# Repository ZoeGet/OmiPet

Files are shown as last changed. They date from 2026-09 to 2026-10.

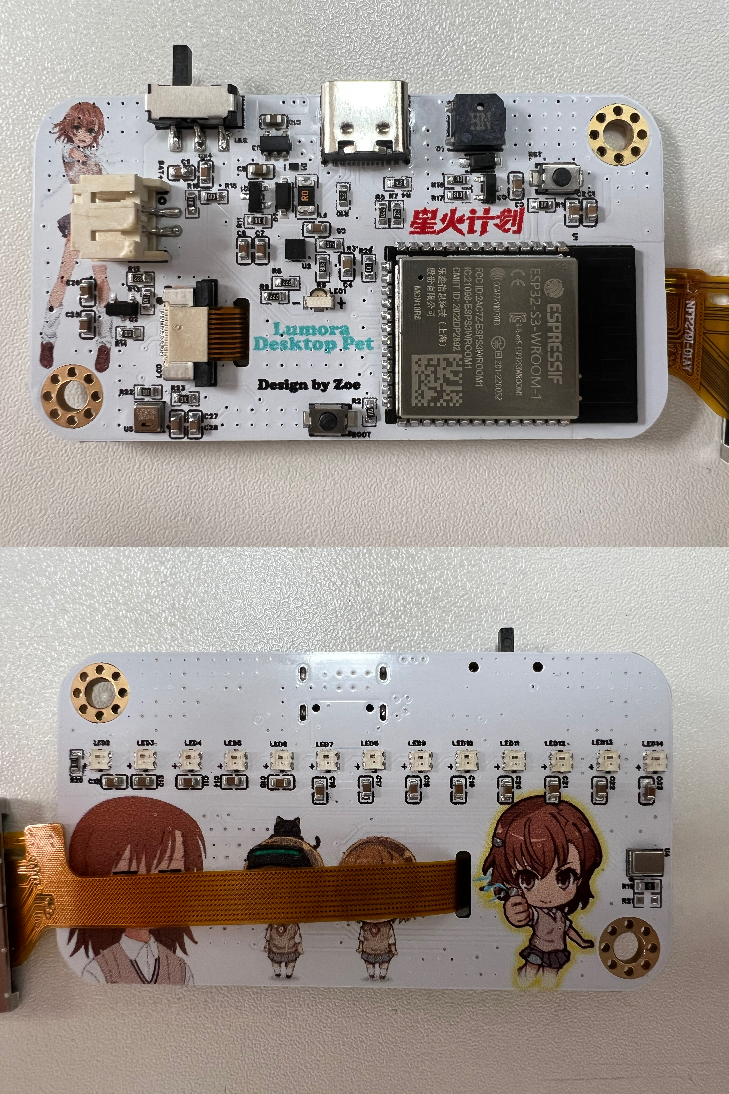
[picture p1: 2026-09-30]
Hardware/Images/Welding.jpg

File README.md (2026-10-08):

# OmiPet

OmiPet 是一个面向桌面陪伴场景的开源软硬件项目：它以 ESP32-S3 为核心，集成横向显示的彩色 LCD、温湿度传感器、灯带、蜂鸣器和数字麦克风，逐步实现桌面宠物、环境感知和离线语音交互。

> **English** — OmiPet is an open-source desktop companion project built around an ESP32-S3. It combines a landscape-oriented color LCD, environmental sensing, addressable LEDs, a buzzer, and an I²S digital microphone with an experimental offline voice interaction path.

## 项目状态 / Project Status

当前项目已经完成基础硬件驱动和第一阶段麦克风采集验证：

- NV3007 `142 × 428` LCD 基础驱动和桌面宠物 UI。
- AHT20 温湿度采集、CRC 校验和整机热影响补偿。
- `13` 颗 WS2812B-2020-V6 灯带驱动。
- 灯带常亮颜色、彩虹、呼吸、左右往返扫描和中心扩散回收动效，并支持离线语音切换。
- 无源蜂鸣器驱动。
- Wi-Fi 异步连接和手机网页配网门户。
- Wi-Fi 连接后通过 NTP 获取本地时间和日期；断网时显示占位符，不使用编译时间或假时间。
- BAT_ADC 电池电压采样和单节锂电估算电量显示；百分比仍需结合实测电池曲线校准。
- ICS-43434 原始 I²S 采集、RMS 音量分析、自适应语音活动检测和 16-bit PCM 音频帧适配。
- ESP-SR v1.2.0 中文 MultiNet `mn6_cn` 命令识别、独立模型分区和自定义短语“老鼠狒狒”实验链路。

当前固件不启用 WakeNet，也不把现成唤醒词冒充为产品唤醒词；“老鼠狒狒”通过中文 MultiNet 自定义命令词表作为唤醒入口，仍属于低延迟和误识别特性待继续验证的实验方案。

> **English** — The current firmware includes the display, environmental sensor, LED strip, passive buzzer, Wi-Fi provisioning, verified ICS-43434 I²S capture, and an ESP-SR v1.2.0 Chinese MultiNet `mn6_cn` command-recognition path using the separate model partition. WakeNet is disabled; “老鼠狒狒” is registered as a custom MultiNet phrase and remains an experimental wake-entry strategy whose latency and false-trigger behavior still require validation.

## 功能概览 / Features

| 模块 / Module | 当前实现 / Current implementation |
| --- | --- |
| 主控 / MCU | ESP32-S3-WROOM-1-N16R8，Arduino + ESP-IDF framework |
| 屏幕 / Display | NV3007，`142 × 428`，4-wire SPI |
| 环境传感器 / Environment | AHT20，I²C，GPIO38/39 |
| 灯带 / LED strip | 13 × WS2812B-2020-V6，GPIO47 |
| 蜂鸣器 / Buzzer | 无源磁式蜂鸣器，GPIO4 控制 / Passive magnetic buzzer on GPIO4 |
| 麦克风 / Microphone | ICS-43434，I²S，GPIO5/6/7 |
| 配网 / Provisioning | WiFiManager 手机网页配网 / WiFiManager captive portal |
| 时间 / Time | NTP 联网校时，默认 UTC+8；离线显示 `--:--` 和 `----/--/--` / NTP time sync, UTC+8 default; placeholders offline |
| 电池 / Battery | GPIO13 分压采样，显示电压和基于单节锂电静置电压的估算百分比 / GPIO13 divider sampling with voltage and estimated single-cell Li-ion percentage |

## 麦克风与 I²S / Microphone and I²S

当前固件使用 ESP32-S3 Arduino 框架内置的 ESP-IDF 旧版 I²S 驱动接口 `<driver/i2s.h>`，没有额外安装 ICS-43434 专用库。驱动直接调用 `i2s_driver_install()`、`i2s_set_pin()` 和 `i2s_read()`。

> **English** — The microphone driver uses the ESP-IDF I²S driver bundled with the ESP32-S3 Arduino framework. No dedicated ICS-43434 library is required.

### 硬件连接 / Hardware mapping

| ICS-43434 信号 / Signal | ESP32-S3 GPIO | 说明 / Description |
| --- | ---: | --- |
| `SCK` / BCLK | `GPIO5` | ESP32-S3 输出位时钟 / Bit clock generated by ESP32-S3 |
| `WS` / LRCLK | `GPIO6` | 字选择时钟 / Word-select clock |
| `SD` | `GPIO7` | 麦克风串行数据输出 / Microphone serial data output |
| `LR` | 由硬件电阻配置 | 决定左/右声道槽 / Selects the left or right I²S slot |

### 当前有效声道 / Active channel

**当前固件明确使用 I²S 右声道槽（`MicChannel::Right`）。**

这是根据当前实物测试确认的：原始双槽数据中只有右声道槽出现非零采样，左声道槽为零。因此 `Firmware/src/main.cpp` 会显式调用：

```cpp
OmiPetAudio::microphone.begin(
    OmiPetAudio::kMicDefaultSampleRateHz,
    OmiPetAudio::MicChannel::Right);
```

对应代码位于 [`Firmware/src/main.cpp`](Firmware/src/main.cpp) 和 [`Firmware/include/ics43434_mic.h`](Firmware/include/ics43434_mic.h)。如果更换 PCB、修改 `LR` 电阻或更换麦克风装配方向，需要重新确认有效声道，并同步修改 `MicChannel::Right`。

> **English** — The current firmware explicitly uses the **right I²S slot** (`MicChannel::Right`). This was verified on the assembled hardware because the right slot contains non-zero samples while the left slot remains zero. Re-check the slot if the PCB `LR` configuration or microphone assembly changes.

### 当前音频参数 / Current audio parameters

- 采样率：`16 kHz` / Sample rate: `16 kHz`
- 接收槽宽：`32-bit` / Receive slot width: `32-bit`
- 有效数据：ICS-43434 的 `24-bit` 数据，固件右移 8 位后用于音量分析 / 24-bit microphone data shifted by 8 bits for level analysis
- 音量窗口：约 `50 ms` / Level window: approximately `50 ms`
- 输出指标：`avg_abs`、`rms`、`peak`、`noise`、`threshold`、`speech`

### 语音交互状态 / Voice interaction state

当前固件使用 `16 kHz`、`16-bit`、单声道 PCM，将每次 `160` 个采样点的输入帧送入 AFE；AFE 以约 `512` 个采样点的输出帧驱动中文 MultiNet `mn6_cn`。词表包含灯带颜色/动效、亮度控制短语和自定义入口“老鼠狒狒”（命令 ID `1`）。识别到入口后，状态机播放约 `180 ms` 的三段式确认反馈，并进入 `LISTENING` 等待灯带控制指令。

### 灯带颜色与动效 / LED Colors and Effects

唤醒后说出颜色或动效命令即可切换灯带。颜色命令会保留当前动效，不会强制切换成常亮；彩色灯光使用彩虹动效，呼吸灯、跑马灯和扩散灯由主循环以非阻塞方式推进，使用约 `12 ms` 的时间驱动帧。三个动效默认使用纯色：呼吸灯为纯蓝、跑马灯为纯绿、扩散灯为纯红；动画只改变亮度，不把其他颜色混入当前颜色。跑马灯和扩散灯始终保留全灯带底光，并用连续渐变高光移动，避免灯珠逐颗跳变或完全熄灭。支持的动效说法包括“彩色”“彩色灯光”“彩色灯”“呼吸灯”“跑马灯”“扩散灯”；RGB 语音词条已删除；颜色命令支持“红色灯光/红色灯”等表达；还支持“开灯”“开启灯光”“一直亮”“关灯”和“关闭灯光”。亮度命令仍以 `16/255` 为步长调整全局亮度，“调亮一点/调暗一点”中的“调”使用拼音 `tiao`。

> **English** — After the custom wake entry, use colorful lights, breathing lights, running lights, or expanding lights. Color commands keep the active effect instead of forcing solid mode. The default effect colors are pure blue for breathing, pure green for running lights, and pure red for expanding lights; animation changes brightness without mixing hues. Running and expanding effects keep a base light on every pixel and add a smooth moving gradient. The brightness commands use `tiao` for 调, as in `tiao liang yi dian` and `tiao an yi dian`.

AFE 和 I²S 始终持续运行，但 VAD 只在检测到语音以及语音结束后的 `1.2 s` 尾窗内调用 MultiNet；这样避免待机时持续推理造成 CPU 调度和看门狗风险，同时尽量保留词尾。该门控策略不会承诺每次都在说话过程中返回，MultiNet 本身仍可能需要积累判定窗口。

> **English** — The firmware uses `16 kHz`, `16-bit`, mono PCM. It feeds `160`-sample input frames into AFE, which produces approximately `512`-sample frames for Chinese MultiNet `mn6_cn`. The phrase list contains brightness commands and the custom “老鼠狒狒” entry (command ID `1`). After detection, the state machine plays an approximately `180 ms` three-phase acknowledgement and listens for natural-language commands such as “亮一点” or “暗一点”.

I²S and AFE remain active continuously, while VAD gates MultiNet detection to speech activity plus a `1.2 s` hangover. This reduces idle inference load and watchdog risk while preserving phrase endings; it does not guarantee that MultiNet returns before the speaker finishes a phrase.

确认音播放期间以及结束后的 200 ms 内，VAD 会暂时抑制语音状态更新，但 I²S/PCM 仍持续采集，避免蜂鸣器回采触发语音开始事件。

> **English** — During the acknowledgement tone and for 200 ms afterward, VAD state updates are temporarily suppressed while I²S/PCM capture continues, preventing buzzer feedback from triggering speech-start events.

## 语音技术栈与唤醒词架构 / Voice Stack and Wake Phrase Architecture

### 技术栈 / Technology stack

当前语音功能采用 **Arduino 应用层 + ESP-IDF 底层 + ESP-SR 语音组件**，不是只依赖 Arduino 库的纯软件实现：

| 层级 / Layer | 当前实现 / Current implementation |
| --- | --- |
| 构建系统 / Build system | PlatformIO，`framework = arduino, espidf` |
| 应用逻辑 / Application logic | Arduino `setup()`/`loop()`、GPIO、灯带、蜂鸣器、UI 和状态机 |
| 音频底层 / Audio layer | ESP-IDF 旧版 I²S 驱动 `<driver/i2s.h>`，驱动 ICS-43434 |
| 语音前端 / Speech front end | ESP-SR AFE，负责音频预处理、AGC 和 VAD |
| 命令识别 / Command recognition | ESP-SR v1.2.0 中文 MultiNet `mn6_cn` |
| 模型存储 / Model storage | `model` 分区中的 SPIFFS 模型镜像 |
| 内存与芯片 / Memory and chip | ESP32-S3-WROOM-1-N16R8，OPI PSRAM，模型和 AFE 缓冲优先使用 PSRAM |

Arduino 负责设备业务和主循环；ESP-IDF 提供 I²S、FreeRTOS 调度和底层硬件接口；ESP-SR 提供 AFE、MultiNet 接口和语音模型。三者是同一份固件中的分层协作关系，不是互相替代的三套方案。

> **English** — The voice feature uses an **Arduino application layer + ESP-IDF low-level APIs + ESP-SR speech components**. Arduino handles `setup()`/`loop()`, device behavior, LEDs, buzzer, UI, and state transitions. ESP-IDF supplies I²S, scheduling, and hardware-level services. ESP-SR supplies the AFE, VAD, MultiNet interfaces, and speech models. This is an Arduino-based application built on the ESP-IDF component layer, not an Arduino-only library implementation.

### 音频处理流程 / Audio processing pipeline

```text
ICS-43434 I²S
    ↓
ESP-IDF I²S RX（GPIO5/GPIO6/GPIO7，16 kHz，32-bit slot）
    ↓
右声道槽提取与 PCM16 转换
    ↓
160-sample PCM frame queue
    ↓
ESP-SR AFE（持续 feed/fetch，包含 VAD）
    ↓
VAD 语音窗口 + 1.2 s 尾窗门控
    ↓
ESP-SR MultiNet `mn6_cn`
    ↓
命令 ID → 唤醒状态机或灯带业务
```

I²S、PCM 队列和 AFE 会持续运行，但 MultiNet 只在检测到语音活动或最近 `1.2 s` 的语音尾窗内进行判定。这样可以避免空闲时持续运行 MultiNet 引起 CPU 调度压力和看门狗风险，同时尽量保留词尾音频。

### “老鼠狒狒”如何实现 / How “老鼠狒狒” is implemented

当前并没有把“老鼠狒狒”写成 WakeNet 模型名称，也没有把它伪装成官方唤醒词。它是中文 MultiNet 命令词表中的一个自定义拼音短语：

```text
1 lao shu fei fei
```

个人配置位于 `Firmware/include/voice_command_config.h`。构建前，`Firmware/scripts/generate_model.py` 会先解析这个文件，将全部命令同步到 `Firmware/scripts/multinet_commands_cn.txt`，再把词表复制到 `target/fst/commands_cn.txt`，生成并加入 PlatformIO 的 `model` 分区镜像。运行时，`Firmware/src/multinet_command_recognizer.cpp` 会通过 ESP-SR 的命令词 API 注册同一组拼音和命令 ID，因此应用固件与模型使用同一份配置。

识别到命令 ID `1` 后，主循环将它解释为自定义唤醒入口：

1. 清空上一段 AFE/MultiNet 上下文；
2. 通知 `VoiceController` 进入 `LISTENING`；
3. 播放非阻塞双音确认反馈；
4. 在超时时间内等待 ID `2` 或 ID `3`；
5. 按 ID `2/3` 将亮度增加或降低 `16/255`，然后回到持续监听。

命令词的唯一修改入口是 `Firmware/include/voice_command_config.h`。修改或新增数组项即可维护唤醒词、同义表达和后续命令；不要直接修改同步后的 `Firmware/scripts/multinet_commands_cn.txt`，也不要修改自动生成的 `Firmware/include/generated_multinet_commands.h`。构建检查会拒绝空配置、重复短语、非正 ID、非法拼音、超过 MultiNet 长度/数量上限的配置，并确保 ID `1/2/3` 仍然存在且 ID `1` 只有一条。

更换或新增步骤：编辑 `Firmware/include/voice_command_config.h` → 修改/增加 `{命令ID, "无声调拼音"}` → 重新构建 → PlatformIO 自动同步词表、生成运行时表并把 `model.bin` 加入烧录列表 → 将应用固件和模型分区一起烧录 → 查看 `[ASR] continuous experiment wake_id=1 phrase=...` 日志并实测。新增命令词会自动注册，但要让设备执行新的业务动作，还必须在 `Firmware/src/main.cpp` 中为该命令 ID 增加业务分派；配置入口不会凭空生成未实现的业务逻辑。

因此，“唤醒词”在当前固件中准确的技术名称是：**MultiNet 自定义命令词入口**，而不是独立的 WakeNet 唤醒模型。

> **English** — “老鼠狒狒” is not a WakeNet model name and is not presented as an official wake word. It is registered as the custom Chinese MultiNet phrase `lao shu fei fei` with command ID `1`. The personal configuration entry is `Firmware/include/voice_command_config.h`; the build synchronizes every configured phrase to the model input, validates limits and IDs, generates the runtime table, and adds the model image to the PlatformIO flash list. New phrases are registered automatically, but a new command ID still needs a corresponding business handler in `Firmware/src/main.cpp`. Changing the tone-free pinyin requires rebuilding and reflashing both the application and the model partition, followed by recognition testing; it is not a runtime setting and arbitrary phrases are not guaranteed to work reliably. The accurate technical description is **a MultiNet custom command entry used as an experimental wake trigger**, not a standalone WakeNet model.

### 为什么不用现成 WakeNet / Why the supplied WakeNet model is not used

WakeNet 是专门的唤醒模型，但当前 ESP-SR 模型包中的现成模型对应固定唤醒短语，例如 `wn9_hiesp` 对应 `Hi ESP`。把配置中的字符串改成“老鼠狒狒”，不会改变神经网络已经训练好的识别目标；真正的自定义 WakeNet 需要与目标短语匹配的定制模型，并且还要重新完成模型打包、容量确认、误唤醒率和漏唤醒率验证。

本项目当前没有“老鼠狒狒”的定制 WakeNet 模型，而项目目标又明确要求自定义唤醒词，因此不能直接使用现成 WakeNet 冒充已经实现了目标词。当前配置明确关闭 WakeNet：`CONFIG_USE_WAKENET=n`，运行时 AFE 配置也设置 `wakenet_init = false`。

选择 MultiNet 自定义命令词作为实验入口，是因为它允许我们在现有中文 `mn6_cn` 模型上注册自己的拼音短语，不需要等待或伪造一个不存在的定制 WakeNet 模型。代价是 MultiNet 不是低延迟专用唤醒引擎：当前实测“老鼠狒狒”通常在语音结束后还要等待约 `1.1–1.3 s`，并且仍需继续验证误识别、误触发和长期稳定性。

> **English** — WakeNet is a dedicated wake-word model, but the bundled model is trained for fixed phrases such as `Hi ESP`. Changing a configuration string does not retrain the neural network. A real custom WakeNet phrase requires a matching custom model, followed by model packaging, capacity checks, false-trigger testing, and missed-wake testing. Because this project does not currently have a custom “老鼠狒狒” WakeNet model, WakeNet is explicitly disabled. MultiNet custom commands provide a workable offline experimental entry, but they are not a low-latency dedicated wake engine; the current measured wake-result delay is typically about `1.1–1.3 s` after speech ends.

### 关键构建文件 / Important build files

- `Firmware/platformio.ini`：声明 Arduino + ESP-IDF 双框架、PlatformIO 环境和模型预构建脚本。
- `Firmware/CMakeLists.txt`：ESP-IDF 工程入口。
- `Firmware/src/CMakeLists.txt`：注册固件源文件并声明 `esp-sr` 组件依赖。
- `Firmware/sdkconfig.defaults`：启用 AFE、中文 MultiNet、模型分区、16 MB Flash 和 OPI PSRAM，并明确关闭 WakeNet。
- `Firmware/components/esp-sr`：ESP-SR v1.2.0 子模块，提供 AFE/MultiNet 头文件、库和模型工具。
- `Firmware/include/voice_command_config.h`：个人语音命令配置入口；集中维护命令 ID 和无声调拼音短语，ID `1` 为唤醒词，ID `2/3` 为亮度，ID `4–16` 为颜色和动效。
- `Firmware/include/led_controller.h`、`Firmware/src/led_controller.cpp`：分离的 WS2812B 硬件缓存 `Strip` 和非阻塞动画控制器 `EffectController`。
- `Firmware/scripts/check_multinet_commands.py`：构建前解析个人配置、同步词表、校验命令 ID/重复短语/容量，并生成 `Firmware/include/generated_multinet_commands.h`。
- `Firmware/scripts/multinet_commands_cn.txt`：由构建流程从个人配置自动同步的 MultiNet 词表，不是推荐的手动编辑入口。
- `Firmware/scripts/generate_model.py`：将 ESP-SR 模型和项目词表打包成 `model.bin`，并将其加入 PlatformIO 烧录流程。

这些文件共同组成当前语音架构；不能因为没有使用 WakeNet 就删除 `CMakeLists.txt`、`sdkconfig.defaults` 或整个 `esp-sr` 目录。

## 硬件资料 / Hardware Resources

- [原理图 / Schematic](Hardware/Schematic/Omi_Schematic.pdf)
- [焊接完成照片 / Assembled board photo](Hardware/Images/Welding.jpg)
- [前壳 / Front cover](Hardware/Enclosure/Frontcover.STEP)
- [后壳 / Back cover](Hardware/Enclosure/Backcover.STEP)

厂家提供的原始 LCD 资料目录不属于公开固件源代码的一部分，相关目录按 `.gitignore` 规则排除，避免将供应商文件和构建产物混入项目仓库。

## 仓库结构 / Repository Layout

```text
OmiPet/
├─ Firmware/                 # PlatformIO firmware / PlatformIO 固件
│  ├─ include/               # Public headers / 公共头文件
│  ├─ lib/                   # Local drivers / 本地驱动
│  ├─ src/                   # Application sources / 应用源码
│  └─ platformio.ini         # Build configuration / 构建配置
├─ Hardware/
│  ├─ Schematic/             # Schematic files / 原理图
│  ├─ Images/                # Board photos / 实物照片
│  └─ Enclosure/             # STEP enclosure models / STEP 外壳模型
├─ README.md
└─ .gitignore
```

## 快速开始 / Quick Start

### 环境要求 / Requirements

- VS Code + PlatformIO
- ESP32-S3-WROOM-1-N16R8 或兼容的 ESP32-S3 开发板
- USB 数据线
- Arduino framework（由 PlatformIO 自动安装）

### 编译、烧录和串口监视 / Build, Upload, and Monitor

在仓库根目录执行：

```powershell
cd Firmware
pio run
pio run -t upload
pio device monitor -b 115200
```

ESP32-S3 使用原生 USB CDC 输出串口日志。当前运行状态可以通过以下日志确认：

```text
[SYS] alive ms=... mic=ok wifi=offline
[TIME] NTP synchronized 2026-10-04 12:34
[MIC] frames=800 avg_abs=... rms=... peak=... noise=... threshold=... speech=no
```

当对着麦克风说话时，`rms` 和 `peak` 应明显上升，并可能出现 `speech=yes`。

首次没有保存 Wi-Fi 配置时，设备会启动配网热点并显示门户地址；使用手机连接热点后，在网页中选择附近 Wi-Fi 并填写密码即可完成配网。

联网后固件通过 `ntp.aliyun.com`、`pool.ntp.org` 和 `time.nist.gov` 获取时间，按 UTC+8 显示；首次同步失败每 10 秒重试，已同步后每 1 小时重新校时。主循环在音频处理前后刷新网络和时间状态，减少语音推理造成的 UI 延迟。只有 Wi-Fi 已连接且 NTP 已同步时才显示时间；Wi-Fi 断开或 NTP 尚未同步时，时间显示为 `--:--`，日期显示为 `----/--/--`，不会回退到编译时间。

## 温湿度补偿说明 / Sensor Compensation

AHT20 上电初期的读数通常接近环境值。随着 ESP32-S3、LCD 背光、电源区域和灯带持续工作，传感器所在 PCB 区域会升温，导致温度偏高；相对湿度也会因此表现为偏低。

当前固件采用针对本设备实测得到的经验补偿：温度约减 `4 °C`，湿度约加 `9 %RH`。这不是 AHT20 厂家提供的固定参数，只适用于当前 PCB、负载、背光、灯带亮度、供电和外壳条件。若这些条件改变，应重新进行现场校准。

> **English** — The temperature and humidity offsets are device-specific field calibration values, not sensor-datasheet constants. Recalibrate them if the thermal layout, load, lighting, power source, or enclosure changes.

## 开发路线 / Roadmap

- [x] NV3007 LCD 基础驱动和 UI / Basic display driver and UI
- [x] AHT20 读取、校验和补偿 / AHT20 reading, validation, and compensation
- [x] WS2812B 灯带驱动 / WS2812B strip driver
- [x] 无源蜂鸣器驱动 / Passive buzzer driver
- [x] Wi-Fi 网页配网 / Wi-Fi captive-portal provisioning
- [x] 联网 NTP 时间和日期显示、每小时复校 / Network NTP time/date display with hourly resynchronization
- [x] ICS-43434 原始 I²S 采集 / Raw ICS-43434 I²S capture
- [x] 音量统计和基础语音活动检测 / Level statistics and basic speech activity detection
- [x] 16-bit PCM 音频帧适配 / 16-bit PCM audio frame adaptation
- [x] VAD 门控的 AFE/MultiNet 语音链路 / VAD-gated AFE/MultiNet voice pipeline
- [x] “老鼠狒狒”自定义短语入口 / Custom “老鼠狒狒” phrase entry
- [x] 唤醒后双音反馈状态机 / Post-wake dual-tone feedback state machine
- [x] MultiNet 自然语言亮度指令 / MultiNet natural-language brightness commands
- [ ] 降低 MultiNet 判定窗口延迟 / Reduce MultiNet decision-window latency
- [ ] 扩展语音驱动的设备动作 / Expand voice-controlled device actions

## 贡献与代码规范 / Contributing and Code Style

欢迎提交 Issue、改进建议和 Pull Request。提交代码前请确保：

- 修改范围聚焦，并说明对应的硬件或软件行为。
- 不提交 PlatformIO 构建目录、串口日志、临时文件、密钥或个人环境配置。
- 新增或修改的代码注释统一使用：`//  中文注释 / English comment`。
- 中文在前、英文在后，使用 `/` 分隔，`//` 后保留两个空格。
- 多行注释、命名空间注释、配置项说明和接口说明遵守同一格式。
- 硬件行为如未经实测确认，应在文档中明确标注为待验证。

更多协作约束见本地 `AGENTS.md`；该文件用于开发交接，默认不纳入公开仓库。

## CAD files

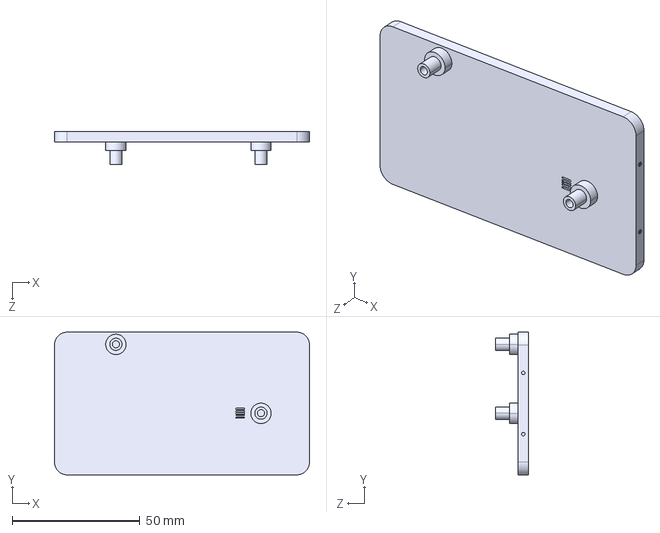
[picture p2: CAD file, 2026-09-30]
Hardware/Enclosure/Backcover.STEP
100.0 x 56.0 x 12.9 mm

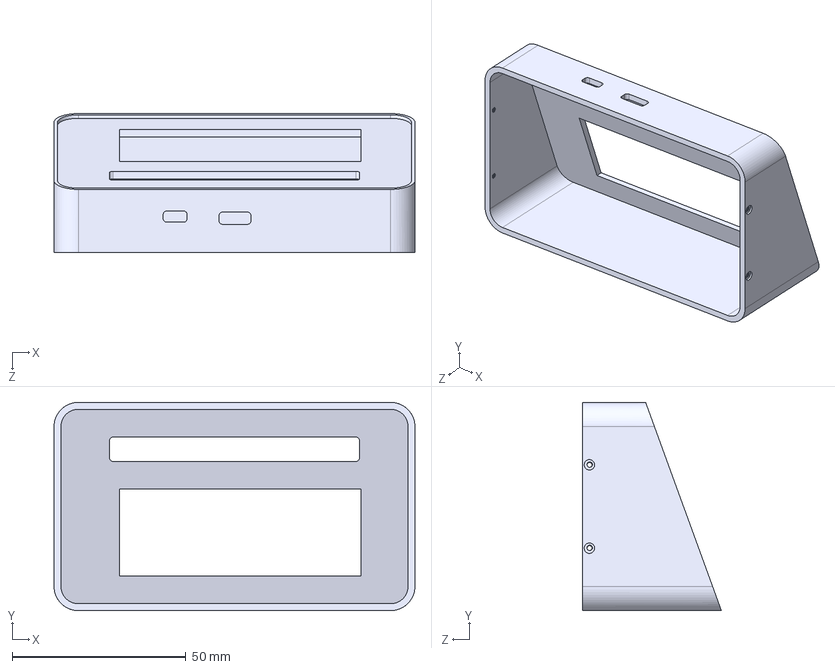
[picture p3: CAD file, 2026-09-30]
Hardware/Enclosure/Frontcover.STEP
104.0 x 60.0 x 40.0 mm

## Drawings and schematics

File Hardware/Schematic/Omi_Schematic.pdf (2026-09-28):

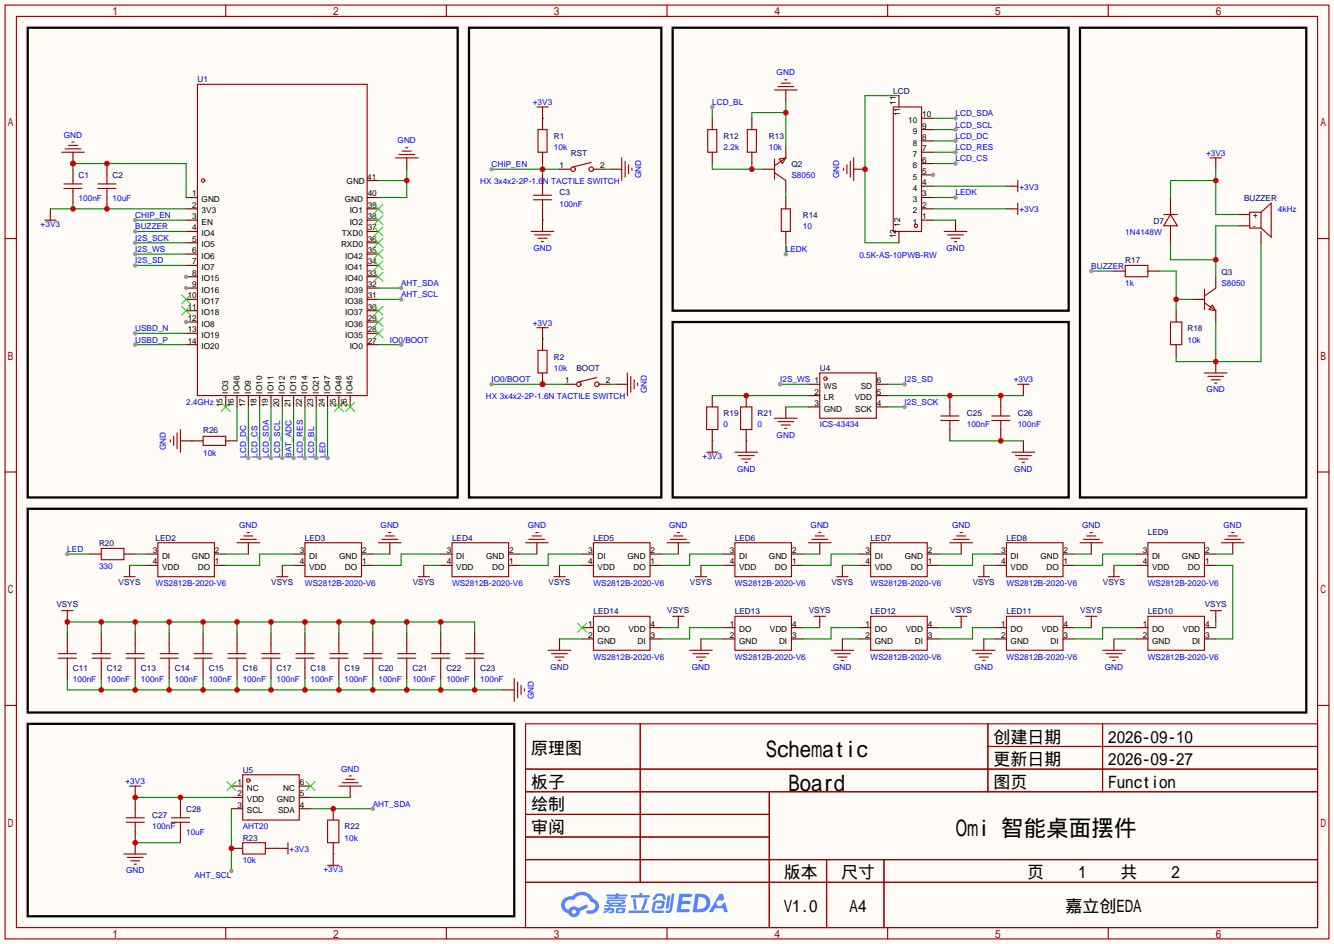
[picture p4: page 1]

原理图 | Schematic | 创建日期 | 2026-09-10

更新日期 | 2026-09-27

绘制 | Omi 智能桌面摆件
审阅

V1.0 | A4 | 嘉立创EDA

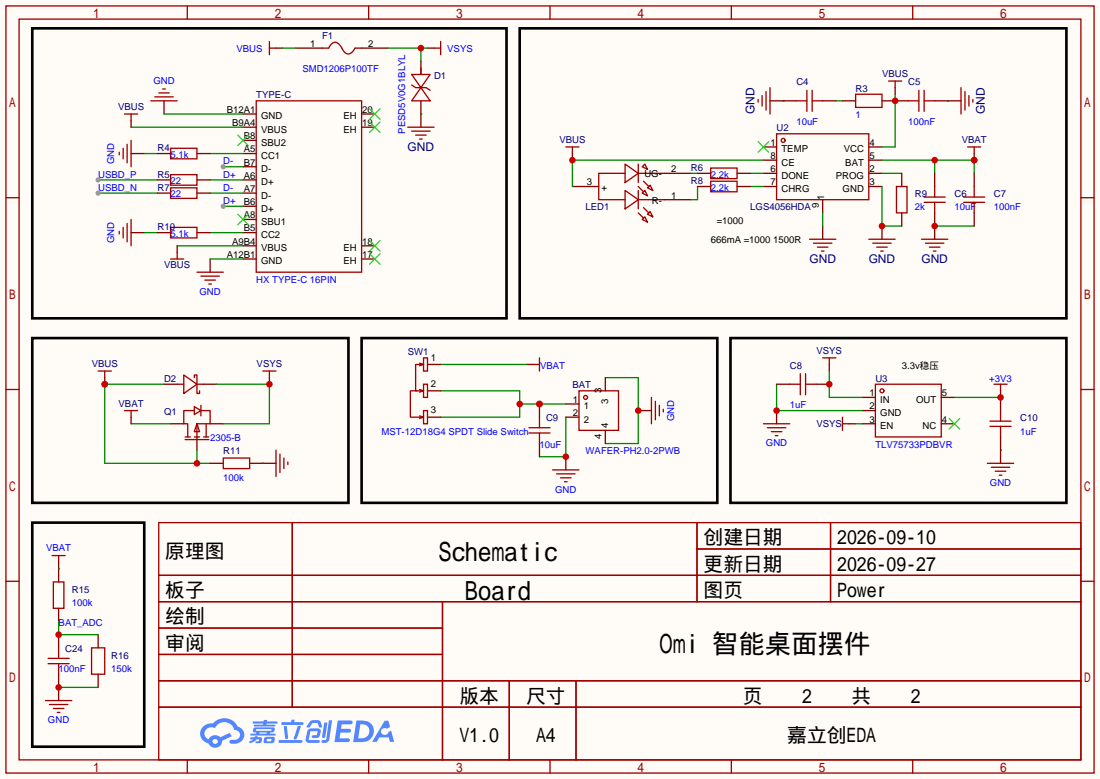
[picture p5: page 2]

MST-12D18G4 SPDT Slide Switch

原理图 | Schematic | 创建日期 | 2026-09-10

更新日期 | 2026-09-27

板子 | Board | 图页 | Power
绘制 | | Omi 智能桌面摆件
审阅

V1.0 | A4 | 嘉立创EDA

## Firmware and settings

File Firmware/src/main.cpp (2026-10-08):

#include <Arduino.h>
#include <algorithm>
#include <cmath>
#include <cstdint>
#include "aht20_sensor.h"
#include "battery_monitor.h"
#include "buzzer.h"
#include "NV3007_Display.h"
#include "led_controller.h"
#include "omi_pet_ui.h"
#include "time_service.h"
#include "wifi_manager.h"

//  OmiPet 固件主循环和模块编排 / OmiPet firmware entry point and module orchestration
#include "ics43434_mic.h"
#include "pcm_audio_frame_buffer.h"
#include "multinet_command_recognizer.h"
#include "voice_controller.h"

namespace {

//  音频链路为 I2S、PCM 队列、AFE、VAD 和 MultiNet 的串联流程 / The audio path chains I2S, PCM queue, AFE, VAD, and MultiNet
//  麦克风诊断窗口和周期参数 / Microphone diagnostic window and periodic timing parameters
constexpr size_t kMicDiagnosticFrameCount = 160;  //  每个麦克风诊断窗口的采样帧数 / Audio frames per microphone diagnostic window
constexpr size_t kMicDiagnosticWordCount = kMicDiagnosticFrameCount * 2;  //  双声道原始槽的样本字数量 / Raw sample words for both channel slots
constexpr uint32_t kMicWindowIntervalMs = 10;  //  麦克风诊断窗口处理间隔 / Microphone diagnostic-window interval
constexpr uint32_t kMicLogIntervalMs = 1000;  //  麦克风诊断日志输出间隔 / Microphone diagnostic log interval
constexpr uint32_t kSpeechDetectionHangoverMs = 1200;  //  语音结束后继续允许 MultiNet 检测的尾窗时间 / MultiNet detection hangover after speech ends
constexpr size_t kMaxCommandFramesPerLoop = 4;  //  单次主循环最多处理的命令音频帧数 / Maximum command audio frames processed per loop
constexpr uint32_t kMinimumSpeechStartRms = 10000;  //  从静音进入语音状态的最小 RMS / Minimum RMS to start speech state
constexpr uint32_t kMinimumSpeechHoldRms = 5000;  //  保持语音状态的最小 RMS / Minimum RMS to hold speech state
constexpr uint8_t kSpeechStartWindowCount = 3;  //  连续语音窗口达到此数后进入语音状态 / Speech windows required to enter speech state
constexpr uint8_t kSpeechEndWindowCount = 8;  //  连续安静窗口达到此数后退出语音状态 / Quiet windows required to leave speech state

//  麦克风采样、噪声底和 VAD 状态 / Microphone samples, noise floor, and VAD state
int32_t gMicDiagnosticWords[kMicDiagnosticWordCount] = {};  //  麦克风双声道原始样本窗口 / Raw stereo microphone sample window
uint32_t gLastMicWindowMs = 0;  //  上一次麦克风窗口处理时间 / Last microphone-window processing time
uint32_t gLastMicLogMs = 0;  //  上一次麦克风日志时间 / Last microphone diagnostic log time
uint32_t gLastSystemHeartbeatMs = 0;  //  上一次系统心跳时间 / Last system heartbeat time
uint32_t gMicNoiseFloorRms = 0;  //  自适应噪声底 RMS / Adaptive microphone noise-floor RMS
bool gMicNoiseFloorInitialized = false;  //  是否已经初始化噪声底 / Whether the noise floor is initialized
uint8_t gSpeechStartWindows = 0;  //  连续语音候选窗口计数 / Consecutive speech-candidate window count
uint8_t gSpeechQuietWindows = 0;  //  连续安静窗口计数 / Consecutive quiet-window count
bool gSpeechActive = false;  //  当前是否处于语音活动状态 / Whether speech is currently active
//  记录最近一次 VAD 语音活动，用于维持检测尾窗 / Track the latest VAD activity to maintain the detection hangover
uint32_t gLastSpeechActivityMs = 0;  //  最近一次语音活动时间 / Most recent speech-activity time
uint32_t gLastMicThreshold = 0;  //  最近一次动态语音判定阈值 / Most recent adaptive speech threshold
bool gLastSpeechCandidate = false;  //  最近一次窗口是否为语音候选 / Whether the latest window was a speech candidate

struct MicLevelStats {
  uint32_t averageAbsolute = 0;  //  窗口平均绝对振幅 / Window average absolute amplitude
  uint32_t rms = 0;  //  窗口均方根音量 / Window root-mean-square level
  uint32_t peak = 0;  //  窗口峰值振幅 / Window peak amplitude
  size_t frameCount = 0;  //  已统计的采样帧数 / Number of sampled frames included
};

MicLevelStats gLastMicStats;

//  命令音频队列和识别时间戳 / Command audio queue and recognition timestamps
OmiPetAudio::PcmAudioFrameBuffer gCommandAudioBuffer;  //  送入 AFE/MultiNet 的 PCM 帧队列 / PCM frame queue feeding AFE/MultiNet
int16_t gCommandPcmFrame[OmiPetAudio::kPcmAudioFrameSamples] = {};  //  当前待处理的 PCM 帧 / Current PCM frame being processed
uint32_t gCommandFrameCount = 0;  //  已处理的命令 PCM 帧数量 / Number of processed command PCM frames
uint32_t gLastAudioFrameLogMs = 0;  //  上一次音频帧日志时间 / Last audio-frame log time
uint32_t gSpeechStartAtMs = 0;  //  当前语音片段开始时间 / Start time of the current speech segment
uint32_t gSpeechStopAtMs = 0;  //  当前语音片段结束时间 / End time of the current speech segment
uint32_t gWakeAcceptedAtMs = 0;  //  最近一次唤醒被状态机接受的时间 / Time when the latest wake was accepted
bool gSpeechTimingValid = false;  //  当前语音时间戳是否有效 / Whether current speech timestamps are valid

//  执行一个已识别的灯带命令 / Execute one recognized LED command
bool executeLedCommand(int commandId) {
  using namespace OmiPetAudio;
  switch (commandId) {
    case kIncreaseBrightnessCommandId: {
      const int updatedBrightness = std::max(
          0, std::min(static_cast<int>(OmiPetLed::strip.brightness()) + 16,
                      255));
      OmiPetLed::strip.setBrightness(static_cast<uint8_t>(updatedBrightness));
      OmiPetLed::strip.show();
      Serial.printf("[LED] brightness=%d command=increase\n",
                    updatedBrightness);
      return true;
    }
    case kDecreaseBrightnessCommandId: {
      const int updatedBrightness = std::max(
          0, std::min(static_cast<int>(OmiPetLed::strip.brightness()) - 16,
                      255));
      OmiPetLed::strip.setBrightness(static_cast<uint8_t>(updatedBrightness));
      OmiPetLed::strip.show();
      Serial.printf("[LED] brightness=%d command=decrease\n",
                    updatedBrightness);
      return true;
    }
    case kRedColorCommandId:
      OmiPetLed::effects.setColor(255, 0, 0);
      Serial.println("[LED] color=red");
      return true;
    case kGreenColorCommandId:
      OmiPetLed::effects.setColor(0, 255, 0);
      Serial.println("[LED] color=green");
      return true;
    case kBlueColorCommandId:
      OmiPetLed::effects.setColor(0, 0, 255);
      Serial.println("[LED] color=blue");
      return true;
    case kYellowColorCommandId:
      OmiPetLed::effects.setColor(255, 160, 0);
      Serial.println("[LED] color=yellow");
      return true;
    case kPurpleColorCommandId:
      OmiPetLed::effects.setColor(180, 0, 255);
      Serial.println("[LED] color=purple");
      return true;
    case kCyanColorCommandId:
      OmiPetLed::effects.setColor(0, 220, 255);
      Serial.println("[LED] color=cyan");
      return true;
    case kWhiteColorCommandId:
      OmiPetLed::effects.setColor(255, 255, 255);
      Serial.println("[LED] color=white");
      return true;
    case kRainbowEffectCommandId:
      OmiPetLed::effects.setRainbow();
      Serial.println("[LED] effect=rainbow");
      return true;
    case kBreatheEffectCommandId:
      OmiPetLed::effects.setBreathe();
      Serial.println("[LED] effect=breathe");
      return true;
    case kSweepEffectCommandId:
      OmiPetLed::effects.setSweep();
      Serial.println("[LED] effect=sweep");
      return true;
    case kCenterExpandEffectCommandId:
      OmiPetLed::effects.setCenterExpand();
      Serial.println("[LED] effect=center_expand");
      return true;
    case kSolidEffectCommandId:
      OmiPetLed::effects.setSolid();
      Serial.println("[LED] effect=solid");
      return true;
    case kOffEffectCommandId:
      OmiPetLed::effects.setOff();
      Serial.println("[LED] effect=off");
      return true;
    default:
      return false;
  }
}

//  计算选定声道的音量统计 / Calculate level statistics for the selected channel
MicLevelStats analyzeMicrophoneLevel(const int32_t* words, size_t wordCount,
                                     OmiPetAudio::MicChannel channel) {
  MicLevelStats stats;
  const size_t selectedSlot = static_cast<size_t>(channel);
  uint64_t absoluteSum = 0;
  uint64_t squareSum = 0;

  const size_t frameCount = wordCount / 2;
  for (size_t frame = 0; frame < frameCount; ++frame) {
    const int32_t rawSample = words[frame * 2 + selectedSlot];
    const int32_t sample = rawSample >> 8;
    const int64_t signedSample = sample;
    const uint64_t magnitude = signedSample < 0
                                   ? static_cast<uint64_t>(-signedSample)
                                   : static_cast<uint64_t>(signedSample);
    absoluteSum += magnitude;
    squareSum += magnitude * magnitude;
    stats.peak = std::max(stats.peak, static_cast<uint32_t>(magnitude));
    ++stats.frameCount;
  }

  if (stats.frameCount == 0U) {
    return stats;
  }

  stats.averageAbsolute =
      static_cast<uint32_t>(absoluteSum / stats.frameCount);
  stats.rms = static_cast<uint32_t>(
      std::sqrt(static_cast<double>(squareSum) / stats.frameCount));
  return stats;
}

//  根据动态噪声底估算语音候选状态 / Estimate speech candidacy from the adaptive noise floor
bool detectSpeech(uint32_t rms, uint32_t& threshold) {
  if (!gMicNoiseFloorInitialized) {
    gMicNoiseFloorRms = rms;
    gMicNoiseFloorInitialized = true;
  }

  const uint32_t thresholdMultiplier = gSpeechActive ? 2U : 3U;
  threshold = std::max(gMicNoiseFloorRms * thresholdMultiplier,
                       gMicNoiseFloorRms + 1000U);
  const uint32_t minimumRms =
      gSpeechActive ? kMinimumSpeechHoldRms : kMinimumSpeechStartRms;
  const bool speechDetected = rms > threshold && rms >= minimumRms;
  if (!speechDetected) {
    gMicNoiseFloorRms = (gMicNoiseFloorRms * 15U + rms) / 16U;
  }
  return speechDetected;
}

//  更新连续语音状态并应用迟滞 / Update continuous speech state with hysteresis
bool updateSpeechState(bool speechCandidate) {
  if (speechCandidate) {
    gSpeechQuietWindows = 0;
    if (!gSpeechActive) {
      if (gSpeechStartWindows < 255U) {
        ++gSpeechStartWindows;
      }
      if (gSpeechStartWindows >= kSpeechStartWindowCount) {
        gSpeechActive = true;
        gSpeechStartWindows = 0;
      }
    }
  } else {
    gSpeechStartWindows = 0;
    if (gSpeechActive) {
      if (gSpeechQuietWindows < 255U) {
        ++gSpeechQuietWindows;
      }
      if (gSpeechQuietWindows >= kSpeechEndWindowCount) {
        gSpeechActive = false;
        gSpeechQuietWindows = 0;
      }
    }
  }
  return gSpeechActive;
}

//  读取麦克风窗口、更新 VAD 状态，并把 PCM 帧送入识别队列 / Read microphone windows, update VAD, and queue PCM frames
//  每 10 ms 处理音频窗口，每秒打印一次诊断状态 / Process an audio window every 10 ms and print diagnostics once per second
void updateMicrophoneDiagnostic() {
  const uint32_t nowMs = millis();
  if (nowMs - gLastMicWindowMs < kMicWindowIntervalMs) {
    return;
  }
  gLastMicWindowMs = nowMs;

  if (!OmiPetAudio::microphone.initialized()) {
    if (nowMs - gLastMicLogMs >= kMicLogIntervalMs) {
      gLastMicLogMs = nowMs;
      Serial.println("[MIC] unavailable");
    }
    return;
  }

  const size_t wordCount = OmiPetAudio::microphone.readRawWords(
      gMicDiagnosticWords, kMicDiagnosticWordCount);
  if (wordCount == 0U) {
    if (nowMs - gLastMicLogMs >= kMicLogIntervalMs) {
      gLastMicLogMs = nowMs;
      Serial.println("[MIC] no samples");
    }
    return;
  }

  gLastMicStats = analyzeMicrophoneLevel(
      gMicDiagnosticWords, wordCount, OmiPetAudio::microphone.channel());
  if (OmiPetAudio::multiNetCommandRecognizer.available()) {
    //  无论是否允许识别，都先把音频送入 AFE 处理链 / Always feed audio into the AFE pipeline, even when detection is gated off
    gCommandAudioBuffer.pushInterleavedWords(
        gMicDiagnosticWords, wordCount, OmiPetAudio::microphone.channel());
  }
  const bool speechWasActive = gSpeechActive;
  if (OmiPetVoice::voice.speechInputSuppressed()) {
    gLastSpeechCandidate = false;
    gSpeechActive = false;
    gSpeechStartWindows = 0;
    gSpeechQuietWindows = 0;
  } else {
    gLastSpeechCandidate =
        detectSpeech(gLastMicStats.rms, gLastMicThreshold);
    if (gLastSpeechCandidate) {
      gLastSpeechActivityMs = nowMs;
    }
    updateSpeechState(gLastSpeechCandidate);
  }
  if (speechWasActive != gSpeechActive) {
    Serial.printf("[VAD] event=%s rms=%lu threshold=%lu\n",
                  gSpeechActive ? "start" : "stop",
                  static_cast<unsigned long>(gLastMicStats.rms),
                  static_cast<unsigned long>(gLastMicThreshold));
    if (gSpeechActive) {
      gSpeechStartAtMs = nowMs;
      gSpeechTimingValid = true;
      Serial.printf("[TIMING] speech_start ms=%lu\n",
                    static_cast<unsigned long>(gSpeechStartAtMs));
    } else {
      gSpeechStopAtMs = nowMs;
      Serial.printf("[TIMING] speech_stop ms=%lu duration_ms=%lu\n",
                    static_cast<unsigned long>(gSpeechStopAtMs),
                    gSpeechTimingValid
                        ? static_cast<unsigned long>(gSpeechStopAtMs -
                                                     gSpeechStartAtMs)
                        : 0UL);
    }
  }
  if (nowMs - gLastMicLogMs < kMicLogIntervalMs) {
    return;
  }
  gLastMicLogMs = nowMs;
  Serial.printf(
      "[MIC] frames=%u avg_abs=%lu rms=%lu peak=%lu noise=%lu threshold=%lu candidate=%s speech=%s start=%u quiet=%u\n",
      static_cast<unsigned>(gLastMicStats.frameCount),
      static_cast<unsigned long>(gLastMicStats.averageAbsolute),
      static_cast<unsigned long>(gLastMicStats.rms),
      static_cast<unsigned long>(gLastMicStats.peak),
      static_cast<unsigned long>(gMicNoiseFloorRms),
      static_cast<unsigned long>(gLastMicThreshold),
      gLastSpeechCandidate ? "yes" : "no",
      gSpeechActive ? "yes" : "no",
      static_cast<unsigned>(gSpeechStartWindows),
      static_cast<unsigned>(gSpeechQuietWindows));
}

//  将连续采集的 PCM 帧送入离线命令识别器 / Submit continuously captured PCM frames to the offline command recognizer
//  AFE 始终接收音频，allowDetection 只控制 MultiNet 是否实际判定 / AFE always receives audio; allowDetection only gates MultiNet decisions
void updateCommandAudioFrames() {
  size_t processedFrameCount = 0;
  while (gCommandAudioBuffer.popFrame(
             gCommandPcmFrame, OmiPetAudio::kPcmAudioFrameSamples) &&
         processedFrameCount < kMaxCommandFramesPerLoop) {
    ++processedFrameCount;
    const uint32_t nowMs = millis();
    //  AFE 持续运行，但只有语音活动或尾窗内才调用 MultiNet 推理 / Keep AFE running continuously, but invoke MultiNet only during speech or hangover
    const bool speechDetectionWindowOpen =
        gSpeechActive ||
        (gLastSpeechActivityMs != 0U &&
         nowMs - gLastSpeechActivityMs <= kSpeechDetectionHangoverMs);
    const bool allowDetection =
        speechDetectionWindowOpen &&
        !OmiPetVoice::voice.speechInputSuppressed();
    const uint32_t detectStartedAtMs = millis();
    const int commandId = OmiPetAudio::multiNetCommandRecognizer.processFrame(
        gCommandPcmFrame, OmiPetAudio::kPcmAudioFrameSamples,
        allowDetection);
    const uint32_t detectFinishedAtMs = millis();
    //  自定义词 ID=1 作为待机入口，识别后清空上一段模型上下文 / Use custom phrase ID 1 as the idle entry and clear the previous model context
    if (commandId == OmiPetAudio::kWakePhraseCommandId &&
        OmiPetVoice::voice.state() == OmiPetVoice::VoiceState::Idle) {
      const uint32_t speechAgeMs =
          gSpeechTimingValid ? detectFinishedAtMs - gSpeechStartAtMs : 0U;
      const uint32_t speechStopAgeMs =
          gSpeechTimingValid && gSpeechStopAtMs >= gSpeechStartAtMs
              ? detectFinishedAtMs - gSpeechStopAtMs
              : 0U;
      Serial.printf(
          "[TIMING] wake_result ms=%lu infer_ms=%lu since_speech_start_ms=%lu "
          "since_speech_stop_ms=%lu\n",
          static_cast<unsigned long>(detectFinishedAtMs),
          static_cast<unsigned long>(detectFinishedAtMs - detectStartedAtMs),
          static_cast<unsigned long>(speechAgeMs),
          static_cast<unsigned long>(speechStopAgeMs));
      OmiPetAudio::multiNetCommandRecognizer.reset();
      gCommandAudioBuffer.reset();
      Serial.println("[VOICE] continuous wake phrase detected");
      if (OmiPetVoice::voice.notifyWakeWordDetected()) {
        gWakeAcceptedAtMs = millis();
        Serial.printf("[TIMING] wake_accepted ms=%lu\n",
                      static_cast<unsigned long>(gWakeAcceptedAtMs));
      }
      continue;
    }
    //  唤醒后接受灯带控制命令，执行成功后回到持续监听 / Accept LED commands after wake-up, then return to continuous listening
    if (OmiPetVoice::voice.listeningForCommand() &&
        commandId >= OmiPetAudio::kIncreaseBrightnessCommandId &&
        commandId <= OmiPetAudio::kCenterExpandEffectCommandId) {
      const uint32_t speechAgeMs =
          gSpeechTimingValid ? detectFinishedAtMs - gSpeechStartAtMs : 0U;
      const uint32_t wakeAgeMs = gWakeAcceptedAtMs != 0U
                                      ? detectFinishedAtMs - gWakeAcceptedAtMs
                                      : 0U;
      Serial.printf(
          "[TIMING] command_result ms=%lu infer_ms=%lu "
          "since_speech_start_ms=%lu since_wake_accepted_ms=%lu\n",
          static_cast<unsigned long>(detectFinishedAtMs),
          static_cast<unsigned long>(detectFinishedAtMs - detectStartedAtMs),
          static_cast<unsigned long>(speechAgeMs),
          static_cast<unsigned long>(wakeAgeMs));
      const bool executed = executeLedCommand(commandId);
      if (!executed) {
        continue;
      }
      Serial.printf("[TIMING] command_executed ms=%lu detect_to_led_ms=%lu\n",
                    static_cast<unsigned long>(millis()),
                    static_cast<unsigned long>(millis() - detectFinishedAtMs));
      OmiPetAudio::multiNetCommandRecognizer.reset();
      OmiPetVoice::voice.notifyCommandCompleted();
    }
    //  每帧主动让出 CPU，确保系统空闲任务和看门狗获得调度 / Yield after each frame so idle tasks and the watchdog can run
    yield();
  }
  gCommandFrameCount += static_cast<uint32_t>(processedFrameCount);

  const uint32_t nowMs = millis();
  if (nowMs - gLastAudioFrameLogMs < kMicLogIntervalMs) {
    return;
  }
  gLastAudioFrameLogMs = nowMs;
  Serial.printf(
      "[AUDIO] command_frames=%lu samples_per_frame=%u rate=%lu channel=right queued=%u dropped=%lu\n",
      static_cast<unsigned long>(gCommandFrameCount),
      static_cast<unsigned>(OmiPetAudio::kPcmAudioFrameSamples),
      static_cast<unsigned long>(OmiPetAudio::kMicDefaultSampleRateHz),
      static_cast<unsigned>(gCommandAudioBuffer.queuedFrames()),
      static_cast<unsigned long>(gCommandAudioBuffer.droppedFrames()));
}
//  处理串口临时唤醒测试命令，不参与正常唤醒路径 / Process the temporary serial wake test command; it is not part of normal wake detection
void updateVoiceDebugInput() {
  while (Serial.available() > 0) {
    const int input = Serial.read();
    if (input == 'w') {
      if (OmiPetVoice::voice.state() == OmiPetVoice::VoiceState::Idle) {
        gCommandAudioBuffer.reset();
        OmiPetAudio::multiNetCommandRecognizer.reset();
        Serial.println("[VOICE] serial wake trigger (debug fallback; continuous recognition active)");
        OmiPetVoice::voice.notifyWakeWordDetected();
      }
    }
  }
}
void refreshNetworkAndTimeUi() {
  const bool wifiConnected = OmiPetNetwork::wifi.connected();
  OmiPetTime::ntp.update(wifiConnected);
  const OmiPetTime::DateTime currentDateTime = OmiPetTime::ntp.current();
  OmiPetUi::setDateTime(currentDateTime.valid, currentDateTime.year,
                        currentDateTime.month, currentDateTime.day,
                        currentDateTime.hour, currentDateTime.minute);
  const String currentWifiSsid = OmiPetNetwork::wifi.ssid();
  OmiPetUi::setNetworkStatus(wifiConnected,
                             OmiPetNetwork::wifi.provisioning(),
                             currentWifiSsid.c_str());
}
//  持续输出系统心跳，帮助区分识别失败和系统停滞 / Print a persistent heartbeat to distinguish recognition failures from a stalled system
void updateSystemHeartbeat() {
  if (millis() - gLastSystemHeartbeatMs < 2000U) {
    return;
  }
  gLastSystemHeartbeatMs = millis();
  Serial.printf("[SYS] alive ms=%lu mic=%s wifi=%s\n",
                static_cast<unsigned long>(millis()),
                OmiPetAudio::microphone.initialized() ? "ok" : "off",
                OmiPetNetwork::wifi.connected() ? "connected" : "offline");
}

}  //  匿名命名空间 / Anonymous namespace
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
void loop() {
  //  处理 WiFiManager 网页配网和连接状态 / Process WiFiManager provisioning and connection state
  OmiPetNetwork::wifi.update();
  refreshNetworkAndTimeUi();
  //  先推进灯效，避免语音识别处理占用主循环时延后动画刷新 / Advance effects first so speech processing delays animation refresh less
  OmiPetLed::effects.update();
  updateSystemHeartbeat();
  updateMicrophoneDiagnostic();
  updateCommandAudioFrames();
  updateVoiceDebugInput();
  const bool wasListeningForCommand =
      OmiPetVoice::voice.listeningForCommand();
  OmiPetVoice::voice.update(gSpeechActive);
  if (wasListeningForCommand &&
      !OmiPetVoice::voice.listeningForCommand()) {
    OmiPetAudio::multiNetCommandRecognizer.reset();
    gCommandAudioBuffer.reset();
  }
  refreshNetworkAndTimeUi();
  //  每 5 秒读取一次温湿度，降低传感器自热和总线占用 / Read every 5 seconds to reduce sensor self-heating and bus usage
  static uint32_t lastSensorReadMs = millis();
  if (millis() - lastSensorReadMs >= 5000U) {
    lastSensorReadMs = millis();
    OmiPetSensor::aht20.readMeasurement();
    const OmiPetSensor::Aht20Measurement& reading =
        OmiPetSensor::aht20.measurement();
    OmiPetUi::setEnvironment(reading.temperatureC, reading.humidityPercent,
                             reading.valid && !reading.stale);
  }
  if (OmiPetBattery::battery.update()) {
    const OmiPetBattery::BatteryMeasurement& batteryReading =
        OmiPetBattery::battery.measurement();
    OmiPetUi::setBatteryStatus(batteryReading.voltageV,
                               batteryReading.percent,
                               batteryReading.valid);
    if (batteryReading.lastReadSucceeded) {
      Serial.printf("[BAT] voltage=%.3fV percent=%u adc_gpio=%u sample=ok\n",
                    batteryReading.voltageV,
                    static_cast<unsigned>(batteryReading.percent),
                    static_cast<unsigned>(OmiPetBattery::kBatteryAdcPin));
    } else {
      Serial.printf("[BAT] sample=failed adc_gpio=%u valid=%s\n",
                    static_cast<unsigned>(OmiPetBattery::kBatteryAdcPin),
                    batteryReading.valid ? "stale" : "no");
    }
  }
  //  维护蜂鸣器非阻塞播放状态 / Maintain the buzzer's non-blocking playback state
  OmiPetBuzzer::buzzer.update();
  OmiPetUi::update();
}

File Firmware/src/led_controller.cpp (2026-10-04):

#include "led_controller.h"

#include <algorithm>
#include <cmath>

namespace OmiPetLed {
namespace {

//  所有动画参数集中放在这里，便于调节速度、柔和度和最低亮度 / Keep animation tuning parameters together for speed, softness, and minimum brightness
//  每 12 ms 最多发送一帧，约等于 83 FPS；动画不依赖 loop() 执行次数 / Send at most one frame every 12 ms, about 83 FPS; animation does not depend on loop count
constexpr uint32_t kFrameIntervalMs = 12;
//  彩虹颜色完成一整圈所需的时间 / Time required for the rainbow hue to complete one full cycle
constexpr uint32_t kRainbowCycleMs = 7200;
//  呼吸灯从暗到亮再回到暗的完整周期 / Full breathing cycle from dim to bright and back to dim
constexpr uint32_t kBreatheCycleMs = 3000;
//  光点从最左移动到最右再返回最左的完整周期 / Full sweep cycle from the left end to the right and back
constexpr uint32_t kSweepCycleMs = 3600;
//  光环从中心扩散到两侧再收回中心的完整周期 / Full cycle for the ring to expand from center and return
constexpr uint32_t kCenterExpandCycleMs = 4200;
//  余弦函数的数学常量 / Mathematical constants used by cosine easing
constexpr float kPi = 3.14159265358979323846F;
constexpr float kTwoPi = 2.0F * kPi;
//  中心扩散灯环保留约 22% 的基础亮度，移动高光只在此基础上叠加 / Keep about 22% base brightness for the center ring and add the moving highlight on top
constexpr float kAnimatedBaseGlow = 0.22F;
//  跑马灯远离高光时仍保留约 10% 亮度，但整条灯带会形成连续渐变 / Keep about 10% brightness away from the sweep highlight for a continuous gradient
constexpr float kSweepMinimumGlow = 0.10F;
//  跑马灯渐变覆盖范围，范围越大，亮暗过渡越宽 / Sweep gradient radius; a larger radius makes the bright-to-dim transition wider
constexpr float kSweepGradientRadius = 7.2F;
//  亮度计算的最低保底值，避免数值取整后完全熄灭 / Minimum level used to prevent rounding from turning a pixel completely off
constexpr uint8_t kAmbientLevel = 7;

//  呼吸灯默认使用纯蓝色；动画只改变亮度，不混入其他颜色 / Use pure blue for breathing by default; animation changes brightness only
constexpr uint8_t kBreatheRed = 0;
constexpr uint8_t kBreatheGreen = 0;
constexpr uint8_t kBreatheBlue = 255;
//  跑马灯默认使用纯绿色；动画只改变亮度，不混入其他颜色 / Use pure green for sweep by default; animation changes brightness only
constexpr uint8_t kSweepRed = 0;
constexpr uint8_t kSweepGreen = 255;
constexpr uint8_t kSweepBlue = 0;
//  扩散灯默认使用纯红色；动画只改变亮度，不混入其他颜色 / Use pure red for center expansion by default; animation changes brightness only
constexpr uint8_t kCenterExpandRed = 255;
constexpr uint8_t kCenterExpandGreen = 0;
constexpr uint8_t kCenterExpandBlue = 0;

//  将数值限制到 0.0 到 1.0，避免浮点误差导致亮度越界 / Clamp a value to 0.0 through 1.0 to prevent brightness overflow
float clampUnit(float value) {
  return std::max(0.0F, std::min(value, 1.0F));
}

//  根据距离计算柔和光晕：中心距离为 0 时最亮，超过半径时为 0 / Calculate a soft glow: brightest at distance 0 and zero beyond the radius
//  余弦曲线在边缘平滑收敛，比线性截断更适合连续灯效 / Cosine easing converges smoothly at the edge and avoids harsh linear cutoffs
float cosineFalloff(float distance, float radius) {
  if (radius <= 0.0F) {
    return 0.0F;
  }
  const float normalizedDistance = clampUnit(distance / radius);
  return 0.5F * (1.0F + std::cos(kPi * normalizedDistance));
}

//  把 0.0 到 1.0 的光晕强度映射到 LED 的 0 到 255 亮度 / Map glow intensity from 0.0 through 1.0 to LED level 0 through 255
//  先加入基础亮度，再四舍五入为整数，减少闪烁和截断误差 / Add ambient brightness first, then round to reduce flicker and truncation error
uint8_t levelFromGlow(float glow) {
  const float level = static_cast<float>(kAmbientLevel) +
                      clampUnit(glow) * (255.0F - kAmbientLevel);
  return static_cast<uint8_t>(std::lround(level));
}

//  在固定底光上叠加高光；高光消失时仍返回基础亮度 / Add a highlight over fixed base light; return the base level even when the highlight fades
uint8_t levelFromHighlight(float highlight) {
  const float base = clampUnit(kAnimatedBaseGlow);
  const float combinedGlow = base + (1.0F - base) * clampUnit(highlight);
  return levelFromGlow(combinedGlow);
}

//  按亮度比例缩放一个 RGB 分量，并保留非零颜色分量避免暗部偏色 / Scale one RGB component while preserving nonzero channels to reduce dark-color shifts
uint8_t scaleComponent(uint8_t component, uint8_t level) {
  if (component == 0U || level == 0U) {
    return 0;
  }
  const uint16_t scaled =
      (static_cast<uint16_t>(component) * level + 127U) / 255U;
  return static_cast<uint8_t>(std::max<uint16_t>(1U, scaled));
}

//  把移动高光转换为跑马灯的连续渐亮渐暗亮度 / Convert the moving highlight into a continuous sweep brightness
uint8_t levelFromSweepGradient(float gradient) {
  const float glow = kSweepMinimumGlow +
                     (1.0F - kSweepMinimumGlow) * clampUnit(gradient);
  return levelFromGlow(glow);
}

}  //  匿名命名空间 / Anonymous namespace

//  创建底层 NeoPixel 对象：13 颗灯、GPIO47、GRB 顺序、800 kHz 协议 / Create the NeoPixel object: 13 LEDs, GPIO47, GRB order, and 800 kHz protocol
Strip::Strip() : pixels_(kLedCount, kDataPin, NEO_GRB + NEO_KHZ800) {}

//  初始化 WS2812B 外设并设置全局亮度 / Initialize the WS2812B peripheral and set global brightness
void Strip::begin(uint8_t brightness) {
  //  初始化 NeoPixel 外设并设置全局亮度；全局亮度由库在发送时统一缩放 / Initialize NeoPixel and set global brightness; the library scales output during transmission
  pixels_.begin();
  setBrightness(brightness);
  //  上电先清空缓存并发送黑帧，避免灯带保留上一次的随机状态 / Clear and transmit a black frame at boot to avoid stale or random LED state
  clear(false);
  show();
}

//  清空灯珠缓存，并按参数决定是否立即发送 / Clear the pixel buffer and optionally transmit immediately
void Strip::clear(bool update) {
  //  clear() 只修改 RAM 缓存；update=true 时才立即把黑帧发送到灯带 / clear() changes only the RAM buffer; update=true also immediately sends the black frame
  pixels_.clear();
  if (update) {
    show();
  }
}

//  把当前缓存发送到灯带硬件 / Transmit the current buffer to the strip hardware
void Strip::show() {
  //  将当前缓存一次性发送给 WS2812B；动画每帧只在这里真正更新硬件 / Transmit the complete buffer to WS2812B; this is the only hardware update per animation frame
  pixels_.show();
}

//  更新 NeoPixel 库使用的全局亮度 / Update the global brightness used by NeoPixel
void Strip::setBrightness(uint8_t brightness) {
  //  这是整条灯带的全局亮度，不会改变动画保存的 RGB 颜色 / This is strip-wide brightness and does not change the RGB color stored by the animation
  brightness_ = brightness;
  pixels_.setBrightness(brightness_);
}

//  返回当前全局亮度值 / Return the current global brightness value
uint8_t Strip::brightness() const { return brightness_; }

//  按 RGB 分量写入一个灯珠缓存 / Write one pixel's RGB components to the buffer
void Strip::setPixel(uint16_t index, uint8_t red, uint8_t green,
                     uint8_t blue) {
  //  先写入缓存，不在单颗灯珠更新时发送；调用方完成整帧后再 show() / Write the buffer without transmitting; the caller calls show() after building the whole frame
  if (index < kLedCount) {
    pixels_.setPixelColor(index, pixels_.Color(red, green, blue));
  }
}

//  按打包颜色值写入一个灯珠 / Write one pixel using a packed color value
void Strip::setPixel(uint16_t index, uint32_t colorValue) {
  //  允许动画直接写入 NeoPixel 打包颜色 / Allow effects to write a packed NeoPixel color directly
  if (index < kLedCount) {
    pixels_.setPixelColor(index, colorValue);
  }
}
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

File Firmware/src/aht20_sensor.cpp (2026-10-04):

#include "aht20_sensor.h"

namespace OmiPetSensor {
namespace {

//  AHT20 状态位和时序参数 / AHT20 status bits and timing parameters
constexpr uint8_t kStatusBusyMask = 0x80;  //  AHT20 状态字节 Busy 位掩码 / AHT20 status-byte busy-bit mask
constexpr uint8_t kStatusCalibrationMask = 0x08;  //  AHT20 状态字节校准使能位掩码 / AHT20 status-byte calibration-bit mask
constexpr uint32_t kPowerUpDelayMs = 100;  //  上电后等待传感器稳定的时间 / Sensor stabilization delay after power-up
constexpr uint32_t kCalibrationDelayMs = 10;  //  发送校准命令后的等待时间 / Delay after sending the calibration command
constexpr uint32_t kMeasurementStartDelayMs = 10;  //  发起测量后开始轮询前的等待时间 / Delay before polling after starting a measurement
constexpr uint32_t kMeasurementConversionDelayMs = 80;  //  测量转换的参考等待时间 / Reference measurement-conversion delay
constexpr uint32_t kMeasurementTimeoutMs = 120;  //  等待 AHT20 空闲的最大时间 / Maximum time to wait for AHT20 readiness
constexpr uint32_t kMeasurementPollIntervalMs = 5;  //  轮询 AHT20 Busy 位的间隔 / AHT20 busy-bit polling interval
constexpr uint32_t kRecoveryFailureThreshold = 3;  //  连续失败后触发软复位的次数阈值 / Consecutive-failure threshold for soft recovery
constexpr uint32_t kRecoveryIntervalMs = 5000;  //  两次自动恢复之间的最小间隔 / Minimum interval between automatic recoveries

//  AHT20 初始化、测量和软复位命令 / AHT20 initialization, measurement, and soft-reset commands
constexpr uint8_t kInitializeCommand[] = {0xBE, 0x08, 0x00};  //  AHT20 初始化校准命令帧 / AHT20 calibration-initialization command frame
constexpr uint8_t kMeasureCommand[] = {0xAC, 0x33, 0x00};  //  AHT20 触发测量命令帧 / AHT20 measurement-trigger command frame
constexpr uint8_t kSoftResetCommand[] = {0xBA};  //  AHT20 软复位命令帧 / AHT20 soft-reset command frame

}  //  匿名命名空间 / Anonymous namespace

//  初始化 AHT20 并完成 I2C 探测和校准 / Initialize AHT20, probe I2C, and complete calibration
bool Aht20Sensor::begin(TwoWire& wire, uint8_t sda, uint8_t scl,
                        uint32_t frequency) {
  //  保存总线配置并清空上一轮状态 / Save bus settings and clear the previous state
  wire_ = &wire;
  sdaPin_ = sda;
  sclPin_ = scl;
  frequency_ = frequency;
  initialized_ = false;
  consecutiveFailures_ = 0;
  measurement_ = Aht20Measurement{};
  clearError();

  //  初始化 I2C 并设置总线频率 / Initialize I2C and set the bus frequency
  wire_->begin(sdaPin_, sclPin_);
  wire_->setClock(frequency_);
  //  等待传感器完成上电 / Wait for the sensor to complete power-up
  delay(kPowerUpDelayMs);

  //  先检测器件，再确认内部校准状态 / Probe the device, then verify internal calibration
  if (!probe() || !ensureCalibration()) {
    return false;
  }

  initialized_ = true;
  return true;
}
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

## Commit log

2026-09-28 feat(firmware): add WS2812B strip driver
2026-09-28 docs(hardware): add schematic archive
2026-09-30 docs(readme): add assembled hardware photo
2026-09-30 docs(hardware): add assembled board photo
2026-09-30 docs(readme): refresh assembled hardware photo
2026-09-30 docs(hardware): add enclosure models
    [Backcover.STEP, Frontcover.STEP]
2026-09-30 feat(display): add NV3007 LCD driver
2026-09-30 docs(display): add NV3007 reference materials
    [NT279VJ-C10-01-V1-结构图.dwg]
2026-09-30 docs(display): preserve vendor STM32 examples
2026-09-30 chore(repo): remove vendor-only LCD materials
    [NT279VJ-C10-01-V1-结构图.dwg]
2026-09-30 feat(sensor): add AHT20 driver
2026-09-30 feat(buzzer): add passive buzzer driver
    [buzzer.cpp, buzzer.h]
2026-09-30 feat(app): integrate sensors and buzzer
    [main.cpp]
2026-09-30 fix(sensor): validate AHT20 measurement status
    [aht20_sensor.cpp, aht20_sensor.h]
2026-09-30 fix(sensor): apply device calibration offsets
    [aht20_sensor.cpp, aht20_sensor.h, main.cpp]
2026-09-30 docs(readme): document sensor thermal compensation
2026-10-01 fix(network): make Wi-Fi startup non-blocking
    [wifi_manager.cpp, wifi_manager.h]
2026-10-01 feat(audio): add native I2S microphone driver
2026-10-01 fix(audio): select verified right I2S slot
    [ics43434_mic.h]
2026-10-01 fix(audio): debounce speech activity detection
    [main.cpp]
2026-10-01 fix(network): retry wifi before provisioning
    [wifi_manager.cpp, wifi_manager.h]
2026-10-01 feat(audio): add wake frame buffering
2026-10-01 fix(voice): shorten and reorder wake tone
    [voice_controller.cpp, voice_controller.h]
2026-10-02 fix(voice): match buzzer acknowledgement pattern
    [voice_controller.cpp, voice_controller.h]
2026-10-02 fix(voice): tune acknowledgement and suppress feedback
    [main.cpp, voice_controller.cpp, voice_controller.h]
2026-10-02 build(esp-sr): add model partition build integration
    [partitions.csv]
2026-10-03 build(voice): configure MultiNet model packaging
    [partitions.csv]
2026-10-03 docs(voice): clarify main audio flow
2026-10-03 docs(config): annotate voice and sensor parameters
2026-10-03 docs(config): annotate sensor and buzzer API parameters
    [aht20_sensor.h, buzzer.h]
2026-10-04 feat(led): add modular controller and smooth effects
2026-10-04 feat(voice): control LED colors and effects
2026-10-04 docs: document LED effects and voice commands
2026-10-04 feat(led): refine colors and voice command names
2026-10-04 docs(led): explain strip and effect internals
2026-10-04 docs(drivers): explain sensor buzzer and wifi flows
    [aht20_sensor.cpp, buzzer.cpp, wifi_manager.cpp]
2026-10-04 fix(ui): clear wifi status area on reconnect
    [main.cpp, wifi_manager.h]
2026-10-04 feat(led): smooth pure-color effects and voice switching
2026-10-04 fix(time): refresh network UI and resync hourly
    [main.cpp]
2026-10-08 fix(wifi): keep nonblocking config portal active
    [wifi_manager.cpp]
2026-10-08 Add battery voltage and charge display
